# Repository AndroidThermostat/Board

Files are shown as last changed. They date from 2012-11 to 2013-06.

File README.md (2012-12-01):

Android Thermostat Board
========================

Circuit board design files for Android Thermostat.

**Important** Make sure the board design files you use match the revision number on the assembly instructions.  The current release designs are Revision A.

License
-------

CERN OPEN HARDWARE LICENCE v1.1

Preamble

Through this CERN Open Hardware Licence ("CERN OHL") version 1.1, the
Organization wishes to disseminate its hardware designs (as published
on http://www.ohwr.org/) as widely as possible, and generally to
foster collaboration among public research hardware designers.  The
CERN OHL is copyright of CERN. Anyone is welcome to use the CERN OHL,
in unmodified form only, for the distribution of his own Open Hardware
designs. Any other right is reserved.  

1 Definitions

In this Licence, the following terms have the following meanings:

“Licence” means this CERN OHL.  

“Documentation” means schematic diagrams, designs, circuit or circuit
board layouts, mechanical drawings, flow charts and descriptive text,
and other explanatory material that is explicitly stated as being made
available under the conditions of this Licence. The Documentation may
be in any medium, including but not limited to computer files and
representations on paper, film, or any other media.  

“Product” means either an entire, or any part of a, device built using
the Documentation or the modified Documentation.  

“Licensee” means any natural or legal person exercising rights under
this Licence.  

“Licensor” means any natural or legal person that creates or modifies
Documentation and subsequently communicates to the public and/ or
distributes the resulting Documentation under the terms and conditions
of this Licence.  

A Licensee may at the same time be a Licensor, and vice versa.

2 Applicability

2.1 This Licence governs the use, copying, modification, communication
to the public and distribution of the Documentation, and the
manufacture and distribution of Products. By exercising any right
granted under this Licence, the Licensee irrevocably accepts these
terms and conditions.  

2.2 This Licence is granted by the Licensor directly to the Licensee,
and shall apply worldwide and without limitation in time. The Licensee
may assign his licence rights or grant sub-licences.  

2.3 This Licence does not apply to software, firmware, or code loaded
into programmable devices which may be used in conjunction with the
Documentation, the modified Documentation or with Products. The use of
such software, firmware, or code is subject to the applicable licence
terms and conditions.  

3 Copying, modification, communication to the public and distribution
of the Documentation

3.1 The Licensee shall keep intact all copyright and trademarks
notices and all notices that refer to this Licence and to the
disclaimer of warranties that is included in the Documentation. He
shall include a copy thereof in every copy of the Documentation or, as
the case may be, modified Documentation, that he communicates to the
public or distributes.

3.2 The Licensee may use, copy, communicate to the public and
distribute verbatim copies of the Documentation, in any medium,
subject to the requirements specified in section 3.1.

3.3 The Licensee may modify the Documentation or any portion
thereof. The Licensee may communicate to the public and distribute the
modified Documentation (thereby in addition to being a Licensee also
becoming a Licensor), always provided that he shall: 
a. comply with section 3.1;
b. cause the modified Documentation to carry prominent notices stating
that the Licensee has modified the Documentation, with the date and
details of the modifications;
c. license the modified Documentation under the terms and conditions
of this Licence or, where applicable, a later version of this Licence
as may be issued by CERN; and
d. send a copy of the modified Documentation to all Licensors that
contributed to the parts of the Documentation that were modified, as
well as to any other Licensor who has requested to receive a copy of
the modified Documentation and has provided a means of contact with
the Documentation.

3.4 The Licence includes a licence to those patents or registered
designs that are held by the Licensor, to the extent necessary to make
use of the rights granted under this Licence. The scope of this
section 3.4 shall be strictly limited to the parts of the
Documentation or modified Documentation created by the Licensor.

4 Manufacture and distribution of Products

4.1 The Licensee may manufacture or distribute Products always
provided that the Licensee distributes to each recipient of such
Products a copy of the Documentation or modified Documentation, as
applicable, and complies with section 3.

4.2 The Licensee is invited to inform in writing any Licensor who has
indicated its wish to receive this information about the type,
quantity and dates of production of Products the Licensee has (had)
manufactured.

5 Warranty and liability

5.1 DISCLAIMER – The Documentation and any modified Documentation are
provided "as is" and any express or implied warranties, including, but
not limited to, implied warranties of merchantability, of satisfactory
quality, and fitness for a particular purpose or use are disclaimed in
respect of the Documentation, the modified Documentation or any
Product. The Licensor makes no representation that the Documentation,
modified Documentation, or any Product, does or will not infringe any
patent, copyright, trade secret or other proprietary right. The entire
risk as to the use, quality, and performance of a Product shall be
with the Licensee and not the Licensor. This disclaimer of warranty is
an essential part of this Licence and a condition for the grant of any
rights granted under this Licence. The Licensee warrants that it does
not act in a consumer capacity.

5.2 LIMITATION OF LIABILITY – The Licensor shall have no liability for
direct, indirect, special, incidental, consequential, exemplary,
punitive or other damages of any character including, without
limitation, procurement of substitute goods or services, loss of use,
data or profits, or business interruption, however caused and on any
theory of contract, warranty, tort (including negligence), product
liability or otherwise, arising in any way in relation to the
Documentation, modified Documentation and/or the use, manufacture or
distribution of a Product, even if advised of the possibility of such
damages, and the Licensee shall hold the Licensor(s) free and harmless
from any liability, costs, damages, fees and expenses, including
claims by third parties, in relation to such use.

6 General

6.1 The rights granted under this Licence do not imply or represent
any transfer or assignment of intellectual property rights to the
Licensee.

6.2 The Licensee shall not use or make reference to any of the names,
acronyms, images or logos under which the Licensor is known, save in
so far as required to comply with section 3. Any such permitted use or
reference shall be factual and shall in no event suggest any kind of
endorsement by the Licensor or its personnel of the modified
Documentation or any Product, or any kind of implication by the
Licensor or its personnel in the preparation of the modified
Documentation or Product.

6.3 CERN may publish updated versions of this Licence which retain the
same general provisions as this version, but differ in detail so far
this is required and reasonable. New versions will be published with a
unique version number.

6.4 This Licence shall terminate with immediate effect, upon written
notice and without involvement of a court if the Licensee fails to
comply with any of its terms and conditions, or if the Licensee
initiates legal action against Licensor in relation to this
Licence. Section 5 shall continue to apply.

6.5 Except as may be otherwise agreed with the Intergovernmental
Organization, any dispute with respect to this Licence involving an
Intergovernmental Organization shall, by virtue of the latter's
Intergovernmental status, be settled by international arbitration. The
arbitration proceedings shall be held at the place where the
Intergovernmental Organization has its seat. The arbitral award shall
be final and binding upon the parties, who hereby expressly agree to
renounce any form of appeal or revision.

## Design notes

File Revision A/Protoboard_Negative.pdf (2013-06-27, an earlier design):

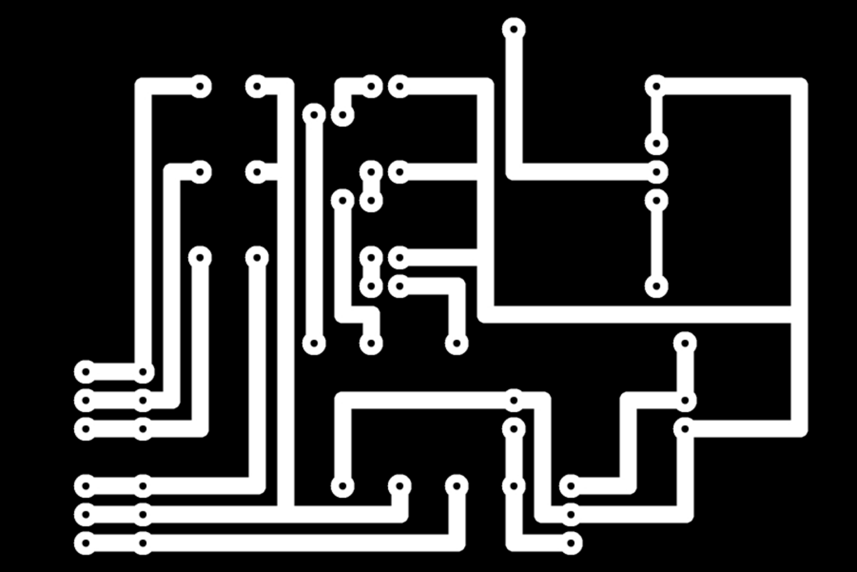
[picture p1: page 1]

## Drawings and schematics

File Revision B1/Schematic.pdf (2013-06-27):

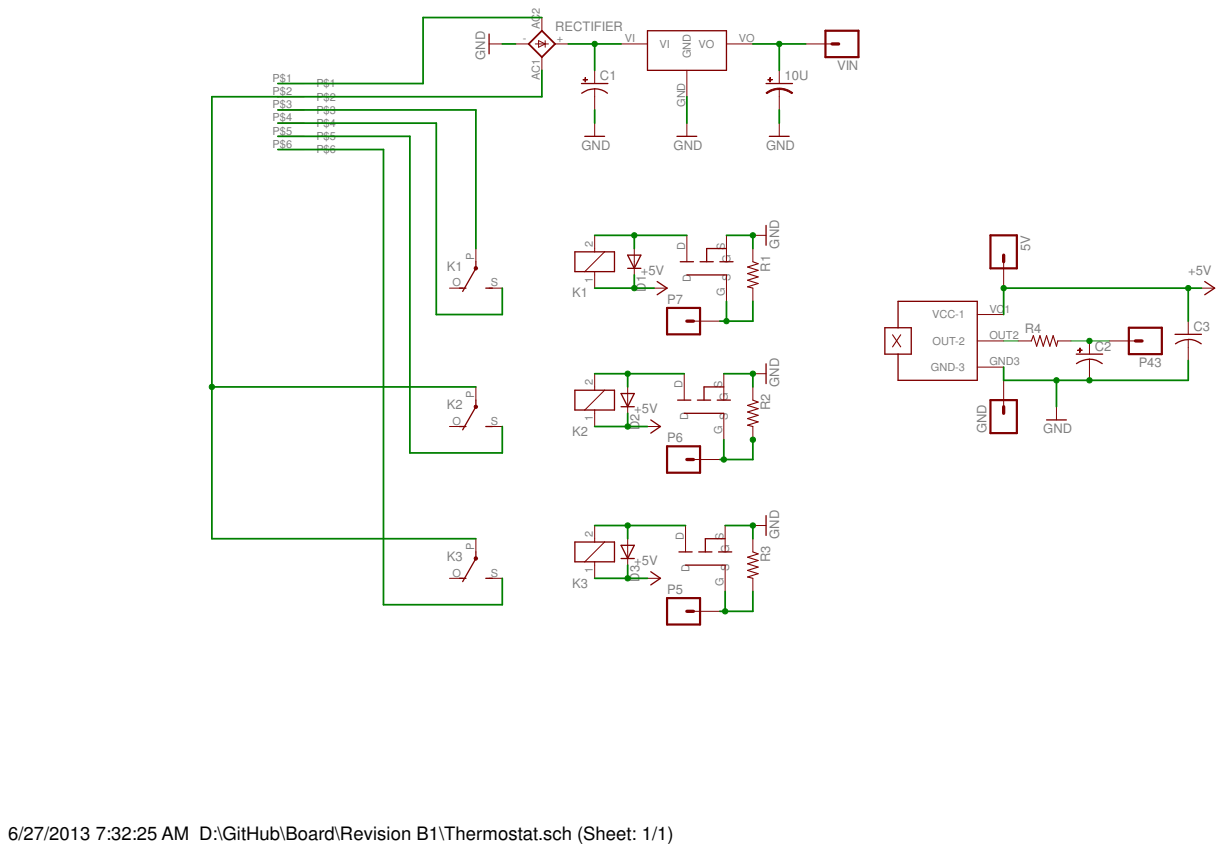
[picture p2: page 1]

6/27/2013 7:32:25 AM D:\GitHub\Board\Revision B1\Thermostat.sch (Sheet: 1/1)

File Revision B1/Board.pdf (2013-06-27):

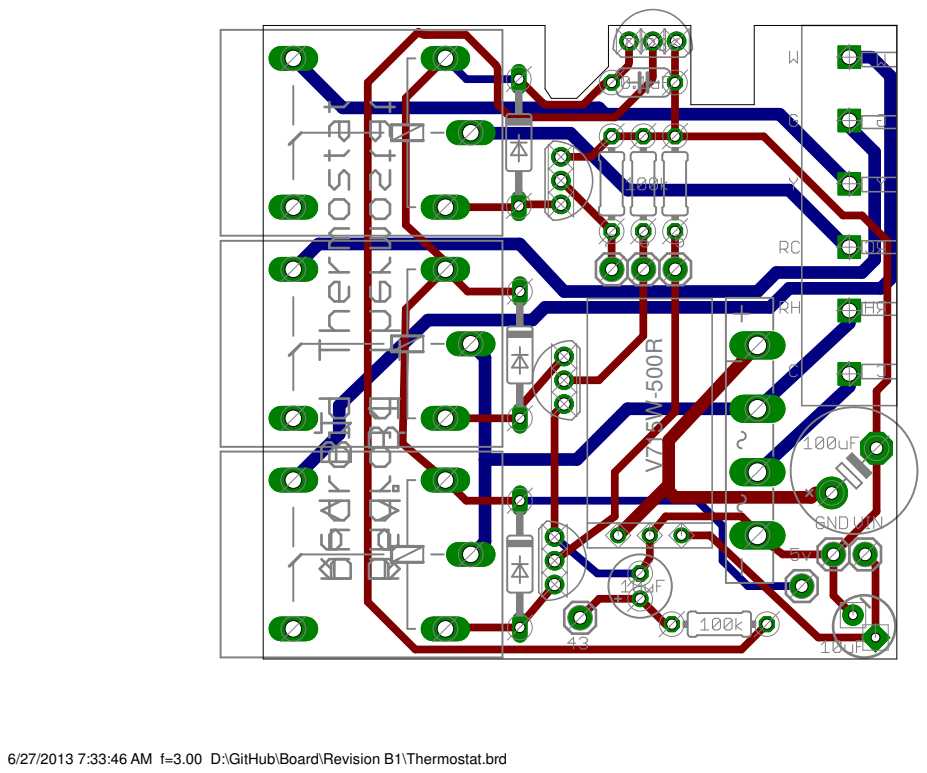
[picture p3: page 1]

6/27/2013 7:33:46 AM f=3.00 D:\GitHub\Board\Revision B1\Thermostat.brd

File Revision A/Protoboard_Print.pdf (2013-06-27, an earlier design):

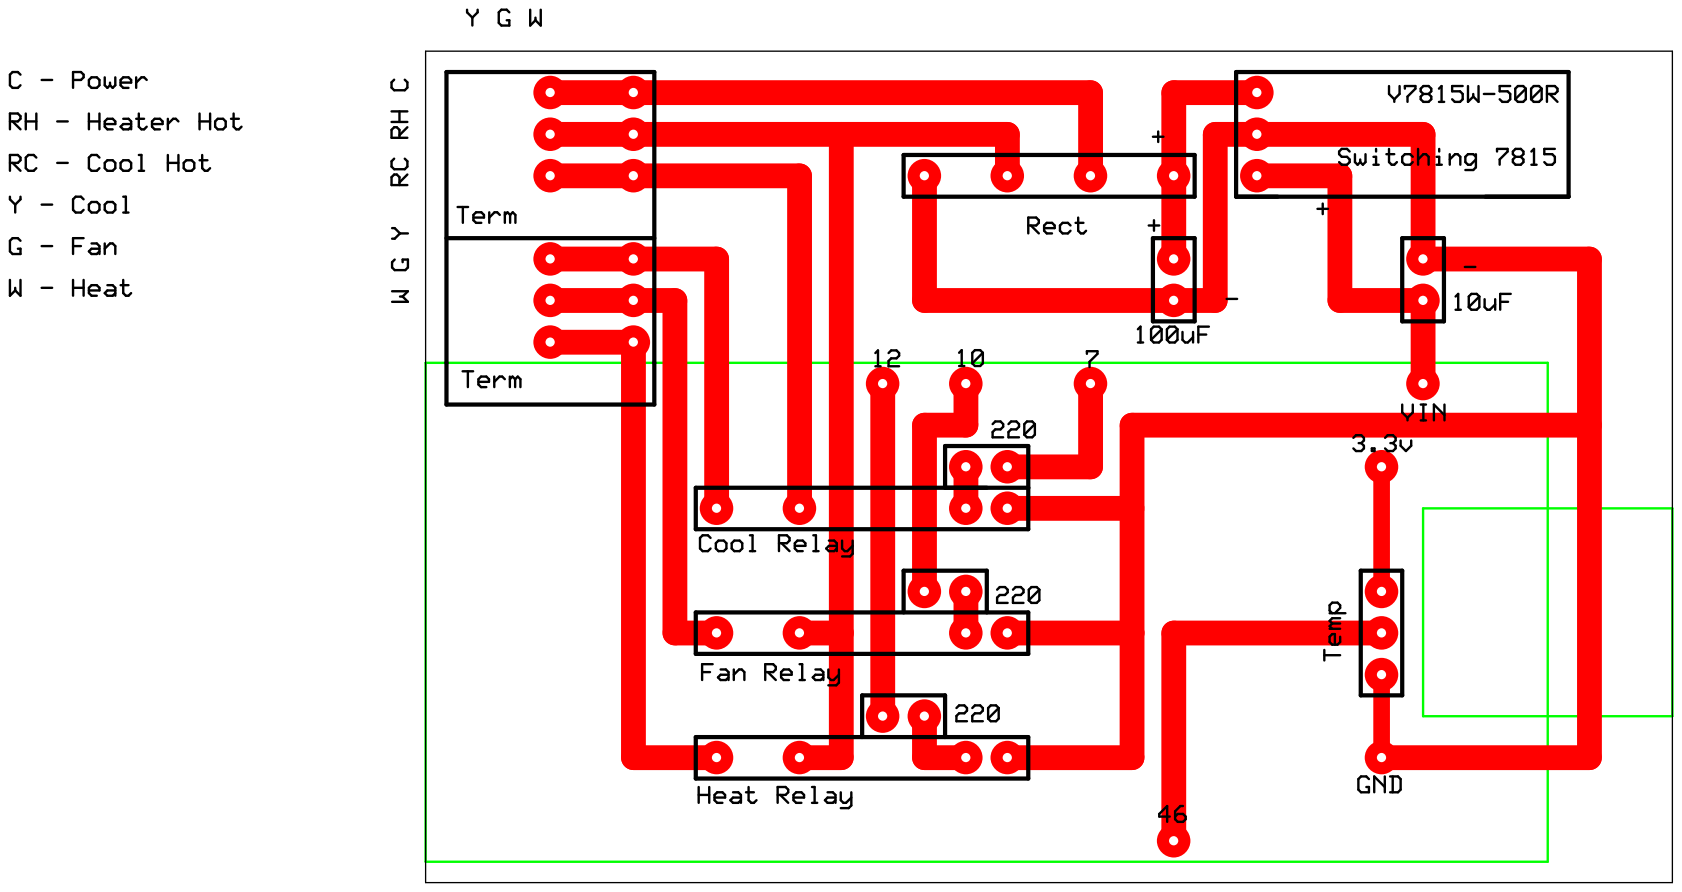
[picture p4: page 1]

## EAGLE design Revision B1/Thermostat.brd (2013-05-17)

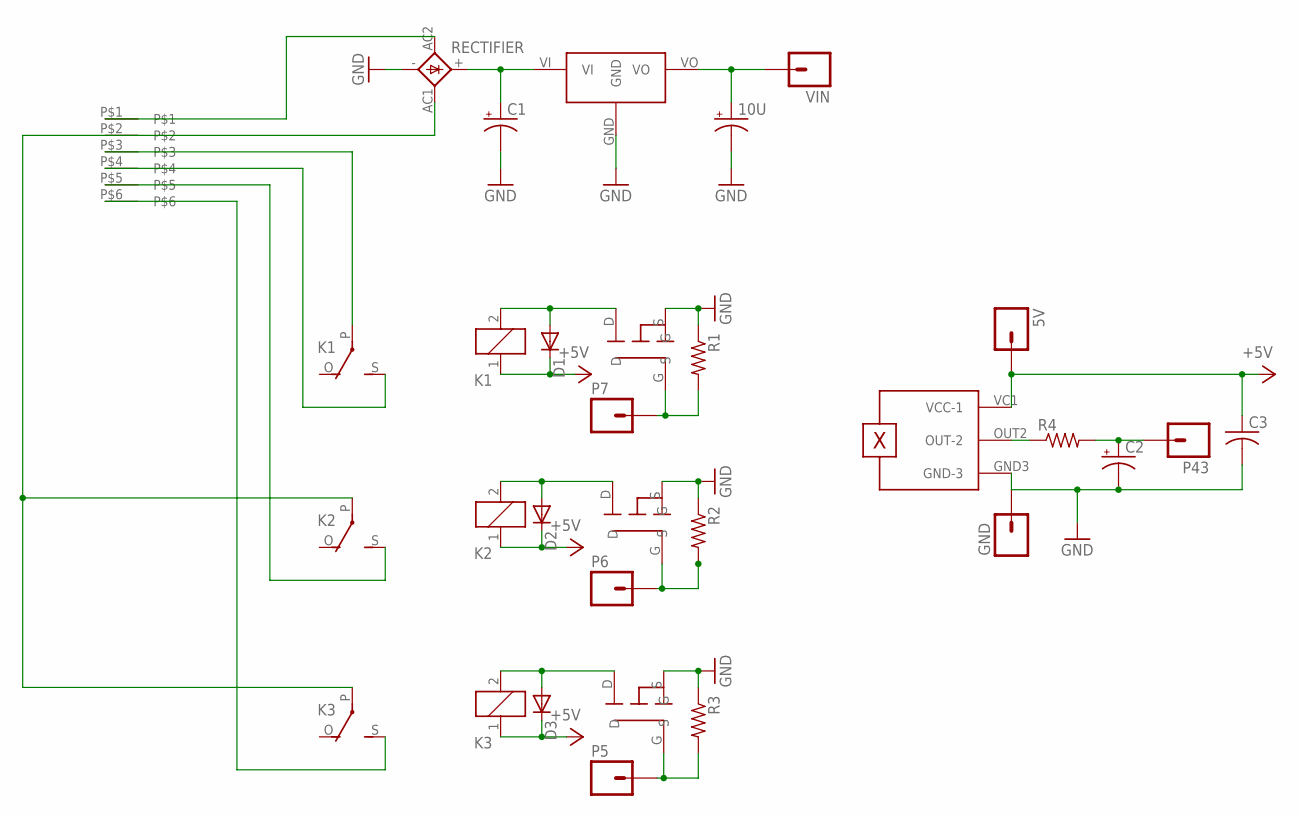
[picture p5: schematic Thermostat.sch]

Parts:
5V: M01PTH; 1X01
10U: CAP_POLPTH2; CPOL-RADIAL-10UF-25V
C1: CPOL-USE5-10.5; E5-10,5
C2: CPOL-USE2-5; E2-5
C3: C-US050-024X044; C050-024X044
D1, D2, D3: 1N4446; DO35-10
GND: M01PTH; 1X01
K1, K2, K3: G5LE
P5, P6, P7, P43: M01PTH; 1X01
R1, R2, R3, R4: R-US_0204/7; 0204/7
RECTIFIER: GBU4; GBU4S
U$1: TMP36
U$2: V715W-500R; SWITCHINGREGULATOR
U$3: PHOENIX-651-1935200; PHOENIX_E_5MM_6PIN
U$4, U$5, U$6: TRANSISTOR
VIN: M01PTH; 1X01

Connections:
+5V: 5V.1, C3.1, D1.C, D2.C, D3.C, K1.1, K2.1, K3.1, U$1.VC1 (VCC-1)
GND: 10U.2 (-), C1.-, C2.-, C3.2, GND.1, R1.1, R2.1, R3.1, RECTIFIER.-, U$1.GND3 (GND-3), U$2.GND, U$4.S, U$5.S, U$6.S
unnamed: K1.P, U$3.P$3
unnamed: P6.1, R2.2, U$5.G
unnamed: D2.A, K2.2, U$5.D
unnamed: C2.+, P43.1, R4.2
unnamed: R4.1, U$1.OUT2 (OUT-2)
unnamed: P7.1, R1.2, U$6.G
unnamed: D1.A, K1.2, U$6.D
unnamed: K2.P, K3.P, RECTIFIER.AC1 (AC2), U$3.P$2
unnamed: 10U.1 (+), U$2.VO, VIN.1
unnamed: K3.S, U$3.P$6
unnamed: K1.S, U$3.P$4
unnamed: K2.S, U$3.P$5
unnamed: P5.1, R3.2, U$4.G
unnamed: D3.A, K3.2, U$4.D
unnamed: RECTIFIER.AC2 (AC1), U$3.P$1
unnamed: C1.+, RECTIFIER.+, U$2.VI

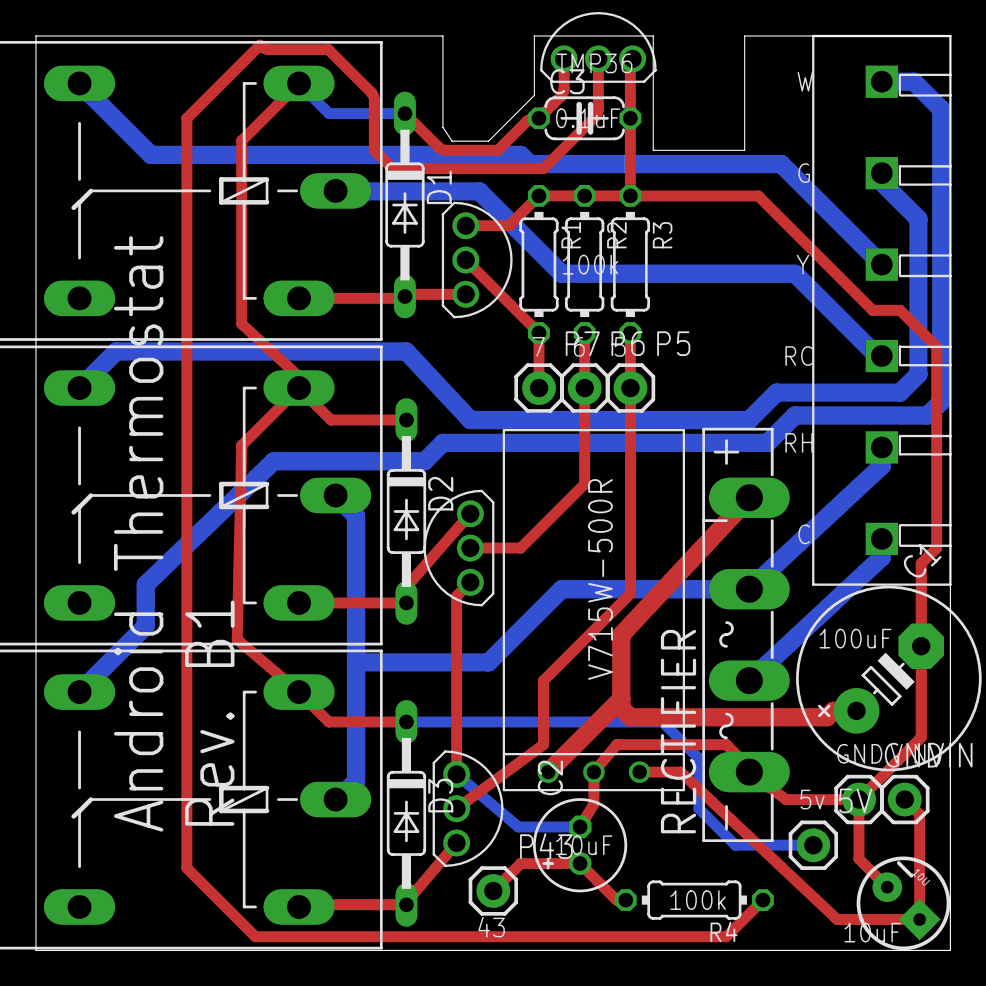
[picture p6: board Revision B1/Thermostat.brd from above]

Board: 2 copper layers, 50.8 x 50.8 mm, 28 parts (0 on the bottom side), 18 nets.

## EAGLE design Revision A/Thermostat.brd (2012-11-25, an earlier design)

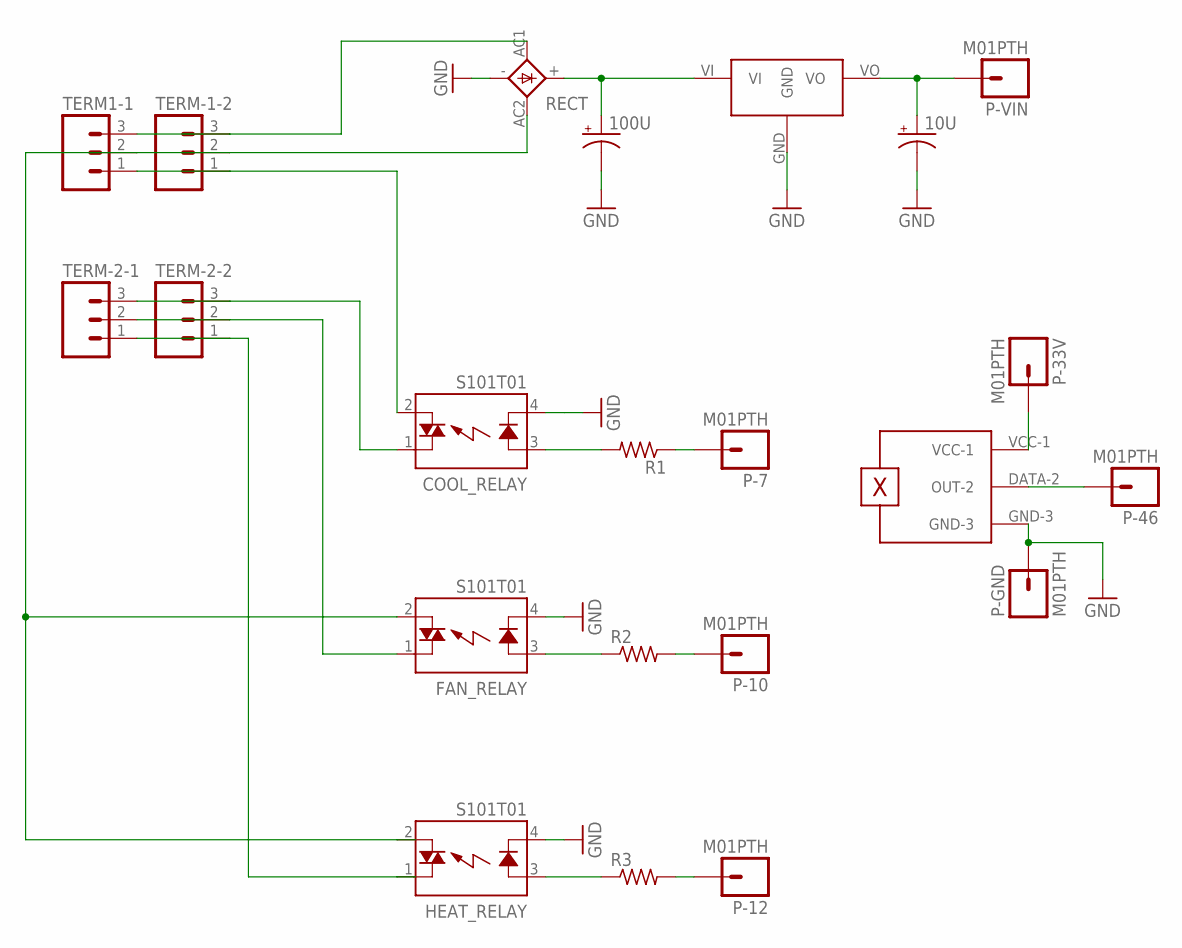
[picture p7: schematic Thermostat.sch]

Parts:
10U: CAP_POLPTH2; CPOL-RADIAL-10UF-25V
100U: CAP_POLPTH1; CPOL-RADIAL-100UF-25V
COOL_RELAY: S101T01; S102T0X
FAN_RELAY: S101T01; S102T0X
HEAT_RELAY: S101T01; S102T0X
P-7, P-10, P-12, P-33V, P-46: M01PTH; 1X01
P-GND: M01PTH; 1X01
P-VIN: M01PTH; 1X01
R1, R2, R3: R-US_0204/2V; 0204V
RECT: GBU4; GBU4S
TERM1-1: M031X03_NO_SILK; 1X03_NO_SILK
TERM-1-2, TERM-2-1, TERM-2-2: M031X03_NO_SILK; 1X03_NO_SILK
U$1: TMP36
U$2: V715W-500R; SWITCHINGREGULATOR

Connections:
GND: 10U.2 (-), 100U.2 (-), COOL_RELAY.4 (K), FAN_RELAY.4 (K), HEAT_RELAY.4 (K), P-GND.1, RECT.-, U$1.GND-3, U$2.GND
unnamed: COOL_RELAY.2 (DS2), TERM1-1.1, TERM-1-2.1
unnamed: HEAT_RELAY.3 (A), R3.1
unnamed: RECT.AC1 (AC2), TERM1-1.3, TERM-1-2.3
unnamed: P-7.1, R1.1
unnamed: P-46.1, U$1.DATA-2 (OUT-2)
unnamed: FAN_RELAY.3 (A), R2.1
unnamed: P-10.1, R2.2
unnamed: P-12.1, R3.2
unnamed: COOL_RELAY.3 (A), R1.2
unnamed: 10U.1 (+), P-VIN.1, U$2.VO
unnamed: P-33V.1, U$1.VCC-1
unnamed: 100U.1 (+), RECT.+, U$2.VI
unnamed: HEAT_RELAY.1 (DS1), TERM-2-1.1, TERM-2-2.1
unnamed: COOL_RELAY.1 (DS1), TERM-2-1.3, TERM-2-2.3
unnamed: FAN_RELAY.1 (DS1), TERM-2-1.2, TERM-2-2.2
P2: FAN_RELAY.2 (DS2), HEAT_RELAY.2 (DS2), RECT.AC2 (AC1), TERM1-1.2, TERM-1-2.2

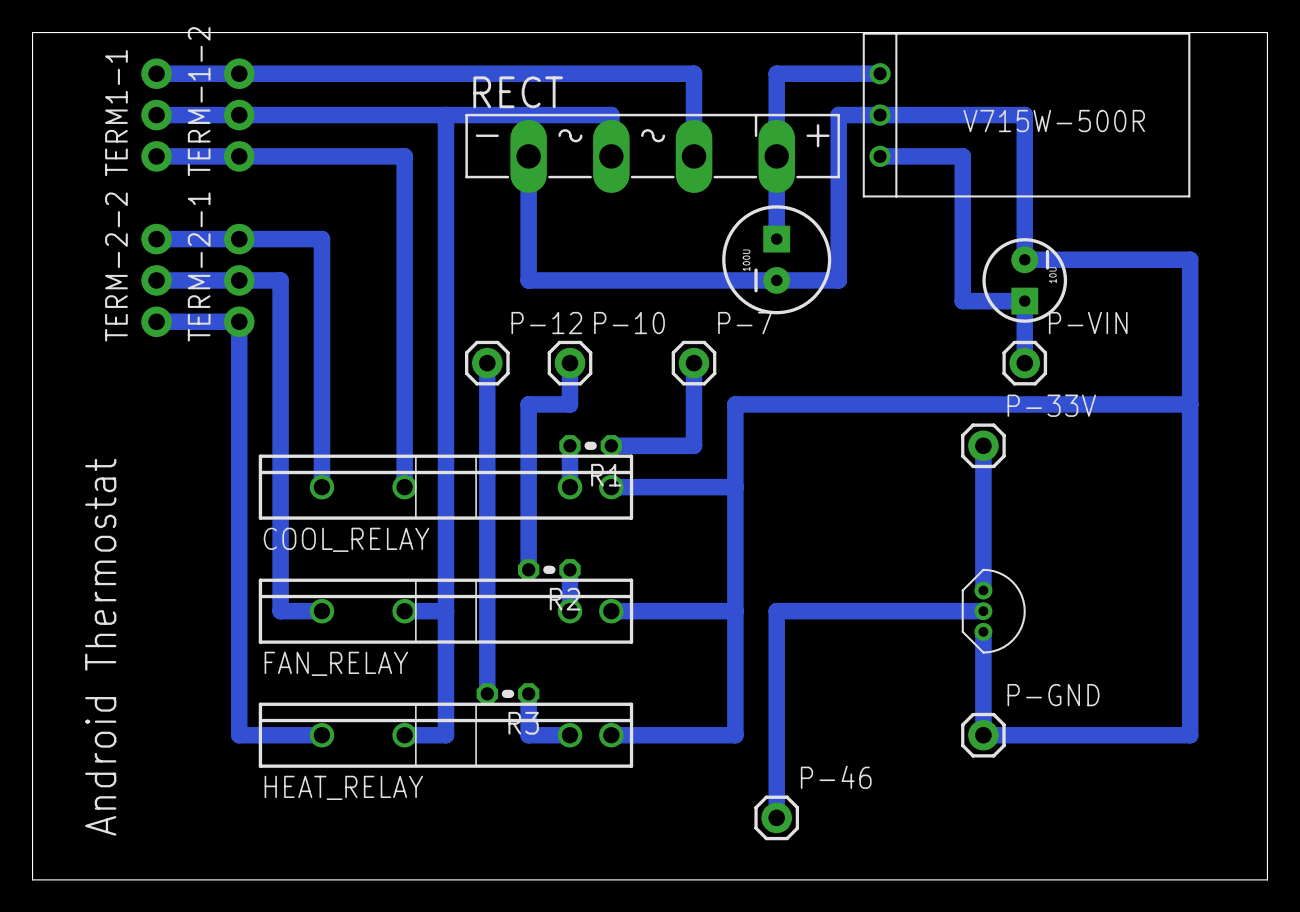
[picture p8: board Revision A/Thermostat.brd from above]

Board: 2 copper layers, 75.9 x 52.1 mm, 22 parts (0 on the bottom side), 17 nets.

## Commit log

2012-11-22 Initial Checkin
    The Eagle files created by Randy Farmer from the PDF and ExpressPCB
    designs posted at AndroidThermostat.com. The design currently contains
    at least two errors with the wrong type of regulator and temperature
    sensor being shown that will need to be corrected.
    [Thermostat.brd, Thermostat.sch]
2012-11-23 Custom Components
    Designed custom components for the temperature sensor and switching
    regulator. Corrected pin 42 to 46. Corrected some mistakes in the
    schematic and re-arranged it. Rewired the board paths to match the
    original published directions. Have not tested printing or alignment
    yet.
    [Thermostat.brd, Thermostat.sch]
2012-11-25 Fixed Alignment
    Moved all of the components to match the published board. Revision A
    should be complete now.
    [Thermostat.brd]
2012-11-27 Started Revision B
    Started the second revison of the circuit board for the IOIO OTG. The
    main goal for this revision is to get the price down as much as
    possible, which includes shrinking the circuit board from 2x3 to 2x3.
    [Thermostat.brd, Thermostat.sch]
2012-11-28 Added Transistors
    The IOIO can only supply 20ma from the digital pins, so I added
    transistors to feed 5v and switched to the 5v relays.
    [Thermostat.brd, Thermostat.sch]
2012-12-01 Finished Board Layout with Transistors
    Changed the transistor symbol.
    Changed wires to routes
    Verified against design rules
    Added top and bottom silk text
    [Thermostat.brd, Thermostat.sch]
2012-12-02 First Test Print
    Added Labels
    Exported Gerber Files
    Ordered Test Print
    Adjusted borders to exact 2"x2" after ordering the print.
    [Thermostat.brd]
2012-12-06 Added Temperature Sensor Capacitor
    Added a capacitor to pin 4 to smooth out the voltage reading from the
    temperature sensor. I still need to calculate exactly what size that
    capacitor should be.
    [Thermostat.brd, Thermostat.sch]
2012-12-06 Added Temperature Sensor Resistor
    Added a 150k resistor to the temperature sensor to drop the amps to 5uA,
    below the 7uA output of the temperature sensor, in order to allow the
    capacitor to charge.
    [Thermostat.brd, Thermostat.sch]
2012-12-23 Made tweeks after first print
    Moved relay bodies off the board to provide more space.
    Widened holes for temp sensor, transistors, capacitor and terminal
    Spread out components that were overlapping.
    Removed wires crossing low-pass filter.
    [Thermostat.brd, Thermostat.sch]
2013-01-06 Prepared for second print
    Moved components to within spacing tolerances.
    Added and moved labels.
    Ordered second print.
    [Thermostat.brd]
2013-01-24 Moved Temperature Pin
    Moved the temperature sensor input from PIN 4 (digital) to PIN 43
    (analog). This required moving a number of components around on the
    board.
    [Thermostat.brd, Thermostat.sch]
2013-02-10 Moved Rectifier
    On the third print the bridge rectifier was too close to the 100uf
    capacitor. I moved it slightly and had to move the regulator and diodes
    as well.
    [Thermostat.brd]
2013-02-19 Moved Temperature Sensor
    It was too close to the switching regulator which is putting out a lot
    of heat.
    [Thermostat.brd]
2013-03-05 Low-pass filter changes
    Made adjustments to the low-pass filter per suggestions at:
    http://www.reddit.com/r/AndroidThermostat/comments/19ntz4/temp_sensor_filter/
    [Thermostat.brd, Thermostat.sch]
2013-03-06 Added Capacitor
    Added a 0.1uF capacitor between the 5v and GND lines on the temperature
    sensor to help avoid fluctuations.
    [Thermostat.brd, Thermostat.sch]
2013-03-06 Fixed Spacing
    One of the pathways was too close to a plate and failed the validation.
    [Thermostat.brd]
2013-05-17 Temperature Sensor Isolation
    Moved AC relay wires away from the temperature sensor and added a
    cut-out to isolate it from heat generated by the relay.
    [Thermostat.brd, Thermostat.sch]
2013-06-27 Added PDFs
    Added PDF versions of the B1 schematic and board, and the Revision A
    protoboard files that were previously only hosted on the website.

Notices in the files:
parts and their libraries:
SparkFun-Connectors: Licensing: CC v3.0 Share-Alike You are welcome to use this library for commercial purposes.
